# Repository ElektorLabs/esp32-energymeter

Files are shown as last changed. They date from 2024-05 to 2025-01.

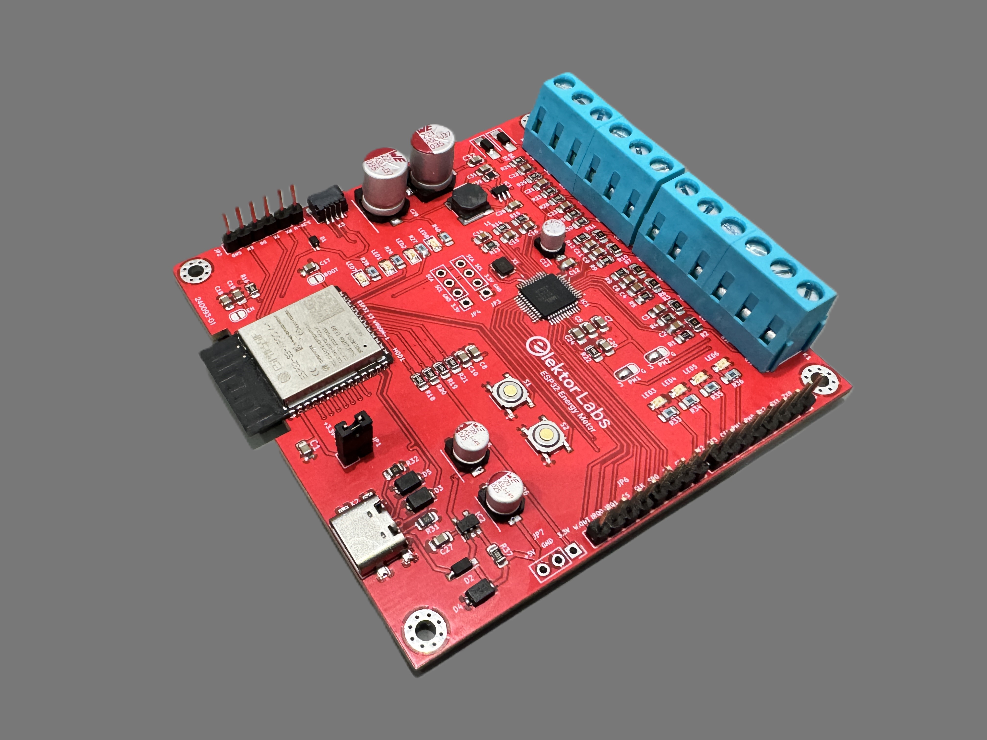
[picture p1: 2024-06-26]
images/IMG_0345.JPG

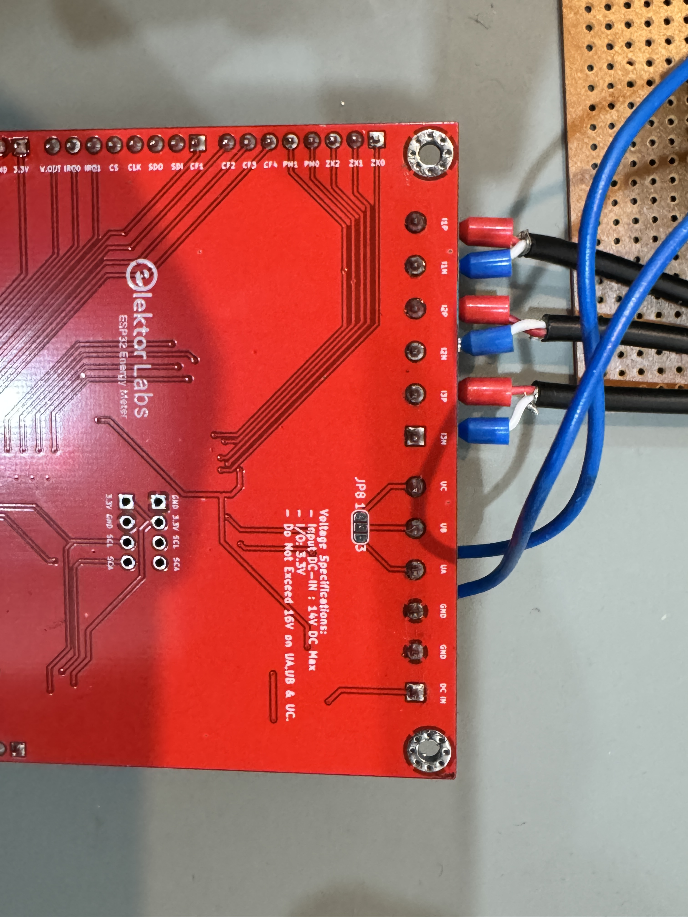
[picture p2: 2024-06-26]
images/IMG_0416.JPG

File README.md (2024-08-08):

# ESP32 Energy Meter

Welcome to the official repository for the ESP32 Energy Meter, an energy monitoring project developed by Elektor Labs. This repository hosts all the necessary design files, code, and documentation to build and deploy a safe energy meter using the ESP32-S3 microcontroller.

## Project Overview

The ESP32 Energy Meter utilizes the Espressif ESP32-S3 microcontroller and the ATM90E32AS IC from Microchip for precise energy measurement across single and three-phase systems. This version includes significant safety and functionality enhancements, including a transformer-based power supply and modularity for diverse applications.

## Features

- **High Precision:** Uses ATM90E32AS IC for accurate energy data.
- **Enhanced Safety:** Transformer-based power reduces direct exposure to high voltages.
- **Flexible Configuration:** Supports both single-phase and three-phase installations.
- **Smart Home Integration:** Easily integrates with Home Assistant for advanced energy management.
- **Customizable Firmware:** Includes ESPHome YAML configurations for easy adaptation and updates.

## Repository Contents

- `/hardware` - Electronic schematic files.
- `/hardware` - PCB design files suitable for manufacturing.
- `/src/ESPHome` - ESPHome YAML configuration files.

## Getting Started

### Prerequisites

Components used in this project are mention in the BOM list `/hardware/production/BOM-esp32-energymeter-V2.xlsx`, overview of the components and required tools are as follows:
- ESP32-S3 module
- ATM90E32AS IC
- Step-down transformer (220V AC to 12V AC) - Preferably a bell transformer
- Current Transfomers - YDHC SCT 013 100A 50mA
- Passive components (resistors, capacitors)
- Tools for PCB assembly and soldering

### Setup Instructions

1. **Clone the repository:**
   ```bash
   git clone https://github.com/ElektorLabs/esp32-energymeter.git
   ```
2. **PCB Assembly:**
   - Refer to the `/hardware` directory and manufacture the PCB using the provided design files.
   - Solder the components onto the PCB as per the layout and schematic details in the `/Schematics` folder.

3. **Firmware Installation:**
   - Navigate to the `/src/ESPHome` directory.
   - Update the YAML file with your specific network details and preferences.
   - Flash the firmware to the ESP32-S3 using ESPHome through the command line or ESPHome Dashboard.

4. **Integrate with Home Assistant:**
   - Follow the integration guide in the article to connect the energy meter to Home Assistant.
   - Monitor and manage your energy consumption directly through the Home Assistant interface.

## Calibration and Testing

- After assembly, perform a calibration check as described in the article to ensure accuracy.
- Test the device under different load conditions to verify the setup and adjust the calibration if necessary.

## Contributing

Your contributions are welcome! If you have enhancements, fixes, or improvements, please fork this repository and submit a pull request with your changes. For substantial modifications or new features, please open an issue to discuss them first.

## License

This project is distributed under the MIT License - see the LICENSE file for details.

## Acknowledgments

- Thanks to Espressif Systems for the ESP32 technology.
- Thanks to Microchip for the energy measurement IC.
- Gratitude to all community members who have contributed to refining this project.

## Contact

For further inquiries or support, feel free to reach out through GitHub issues or the project discussion board.

---

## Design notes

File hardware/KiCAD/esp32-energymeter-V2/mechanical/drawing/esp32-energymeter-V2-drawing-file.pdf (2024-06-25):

3

2

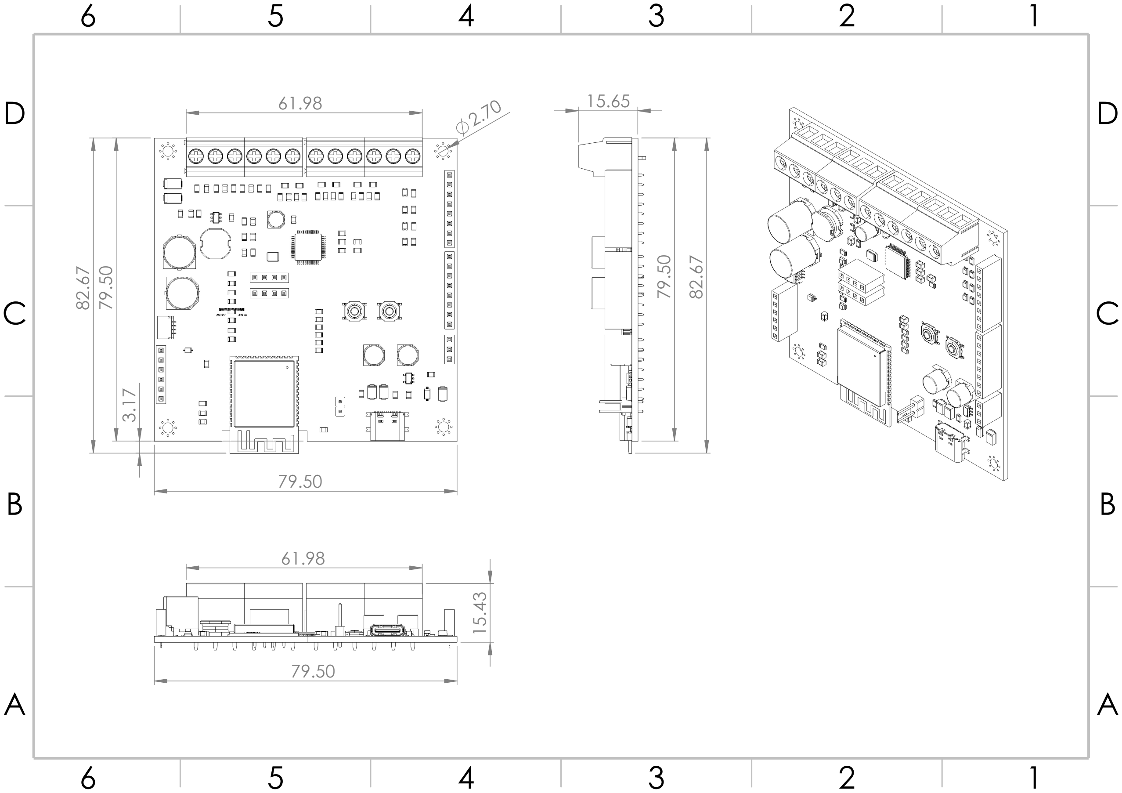
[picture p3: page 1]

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
2.70 82.67

### 79.50 ⁷⁹.50 3.17

61.98 82.67

15.65 79.50

79.50 15.43

61.98

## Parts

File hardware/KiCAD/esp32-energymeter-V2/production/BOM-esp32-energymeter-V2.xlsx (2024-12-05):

Date: | 2024-03-01 16:43
Ref | Mouser Number | Qty | Value | Description
C1, C5, C7, C8, C10, C12, C17, C18, C19, C20, C24, C27, C28, C31, C32 | 80-C0805C104M5RAC | 15 | 100nF | Unpolarized capacitor
C2, C3, C4, C6, C9, C11, C14, C15, C16, C21, C22, C23 | 80-C0805C183K2RACTU | 12 | 18nF | Unpolarized capacitor
C13 | 710-865090340001 | 1 | 4.7uF | Wurth Elektronik 4.7uF 16 V dc Aluminium Electrolytic Capacitor, WCAP-ASLU Series 1000h 5.5 (Dia.) x 3.85mm
C25, C26 | 710-865080442004 | 2 | 22uF | Wurth Elektronik 22uF Electrolytic Capacitor 25V 20% Surface Mount - 865080442004
C29, C30 | 710-865080553014 | 2 | 220uF | Wurth Elektronik 220uF 35 V dc Aluminium Electrolytic Capacitor, WCAP-ASLI Series 2000h 8 (Dia.) x 10.35mm
D1 | 621-BAT760-7 | 1 | BAT760-7 | Diode Schottky 30V 1A 2Pin SOD323 Diodes Inc BAT760-7, SMT Schottky Diode, 30V 1A, 2-Pin SOD-323
D2 | 621-1N5819HW-F | 1 | 1N5819HW-7-F | Diode Schottky 1A 40V SOD123 Diodes Inc 1N5819HW-7-F, SMT Schottky Diode, 40V 1A, 2-Pin SOD-123
D3, D4, D5 | 576-SZSMF4L5.0AT3G | 3 | SZSMF4L5.0AT3G | Automotive Surface Mount 400 W TVS Diode in SOD-123FL
D6,D7 | 621-B140HW-7 | 1 | B140HW-7 | Diodes Inc B140HW-7, SMT Schottky Diode, 40V 1A, 2-Pin SOD-123
IC1 | 556-ATM90E32AS-AU-R | 1 | ATM90E32AS-AU-R
IC2 | 513-NJM2882F33-TE1 | 1 | NJM2882F33-TE1 | LDO Voltage Regulators 75dB 30uVrms 300mA 1.0uF 3.3V 350mW
IC3 | 621-AP63203WU-7 | 1 | AP63203WU-7 | Switching Voltage Regulators DCDC Conv HV Buck TSOT26 T&R 3K
K1, K4 | 490-TB004-508-06BE | 2 |  | Terminal block, screw type, 5.08 , horizontal, 6 poles, CUI Blue
K2 | 523-GSB1C41110SSHR | 1 | GSB1C41110SSHR | USB2.0, Type C, Top mount, Center Height 1.63mm, Single Row Surface Mount
L1 | 652-SRN6028C-3R9M | 1 | 3.9uH | Ind,6.0x6.0x2.6mm,3.9uH+/-20%,3.3A,shd
LED3, LED4, LED5, LED6 | 710-150080YS75000 | 4 | Yellow Led | Light emitting diode
MOD1 | 356-ESP32-S3WRM1N8R2 | 1 | ESP32-S3-WROOM-1 | 2.4 GHz WiFi (802.11 b/g/n) and Bluetooth Â® 5 (LE) module Built around ESP32S3 series of SoCs, Xtensa Â® dualcore 32bit LX7 microprocessor Flash up to 16 MB, PSRAM up to 8 MB 36 GPIOs, rich set of peripherals Onboard PCB antenna
R1, R4, R5, R8, R9, R12, R13, R14, R15, R23, R24, R25 | 652-CHP0805FX1001ELF | 12 | 1k | Resistor
R2, R3, R6, R7, R10, R11 | 755-SDR10EZPJ2R4 | 6 | 2R4 | Resistor
R16, R18, R19, R20, R21, R22 | 652-CMP0805-FX-1002L | 6 | 10k | Resistor
R28, R29, R30, R37 | 652-CMP0805-FX-1003L | 4 | 100k | Resistor
R31, R32 | 755-SDR10EZPJ472 | 2 | 4.7k | Resistor
R26, R27, R33, R34, R35, R36, R38, R40 | 660-RK73H2ATTD80R6F | 8 | 80R | Resistor
R39 | 71-RCS08050000Z0EA | 1 | 0R | Resistor
S1, S2 | 611-PTS526SM15SMTR2L | 2 |  | Tactile Switches 50mA 12VDC, 5.2x5.2mm, 1.5mm H, 160gf, G leads, No ground pin, metal actuator
X1 | 815-ABM8G-16.3-B4Y-T | 1 |  | 16.384 MHz +/-30ppm Crystal 10pF 80 Ohms 4-SMD, No Lead
LED1, LED 7, LED 8 | 710-150080RS75000 | 3 | Red | Light emitting diode
LED2 | 710-150080GS75000 | 1 | Green Led
JP1 |  | 1 |  | PinHeader_1x02_P2.54mm_Vertical
JP2 |  | 1 |  | PinHeader_1x06_P2.54mm_Vertical
JP3 |  | 1 |  | PinHeader_1x04_P2.54mm_Vertical
JP4 |  | 1 |  | PinHeader_1x04_P2.54mm_Vertical
JP5, JP6 |  | 2 |  | PinHeader_1x08_P2.54mm_Vertical
JP7 |  | 1 |  | PinHeader_1x03_P2.54mm_Vertical
Options for Step Down Voltage Transformers
Navaris deurbeltransformator - 8V, 12V, 24V |  | https://amzn.eu/d/h4jTlUE
Honeywell E3539N beltransformator VDE 2 - 12V |  | https://amzn.eu/d/geya4uD
Honeywell E3554N Klingeltransormator VDE 3 - 8V |  | https://amzn.eu/d/geya4uD
Current Transformer
YHDC SCT 013 100A-50mA |  | https://www.poweruc.pl/products/split-core-current-transformer-sct013-rated-input-5a-100a

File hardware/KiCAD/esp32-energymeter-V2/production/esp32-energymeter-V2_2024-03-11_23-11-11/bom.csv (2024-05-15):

Designator | Footprint | Quantity | Value | LCSC Part #
BOOT1 | SolderJumper-2_P1.3mm_Open_RoundedPad1.0x1.5mm | 1 | BOOT
C1, C10, C28, C32, C8 | 0805 | 5 | 100nF 50V
C11, C14, C15, C16, C2, C3, C4, C6, C9 | 0805 | 9 | 18nF
C12, C17, C18, C19, C5 | 0805 | 5 | 0.1uF
C13 | CAPAE430X550N | 1 | 10 uF
C20, C24, C31 | 0805 | 3 | 100nF
C21, C22, C23 | 0805 | 3 | 18nF 50V
C25, C26 | CAPAE530X550N | 2 | 22uF
C27 | 0805 | 1 | 0.01uF
C29, C30 | CAPAE830X1050N | 2 | 220uF
C7 | 0805 | 1 | 10uF 10V
D1 | SOD2513X120N | 1 | BAT760-7
D2 | SOD3716X145N | 1 | 1N5819HW-7-F
D3, D4, D5 | SODFL3824X140N | 3 | SZSMF4L5.0AT3G
D6, D7 | D_SMA | 2 | B140HW-7
EN1 | SolderJumper-2_P1.3mm_Open_RoundedPad1.0x1.5mm | 1 | EN
H1, H2, H3, H4 | MountingHole_2.7mm_Pad_Via | 4 | MountingHole_Pad
IC1 | QFP50P900X900X120-48N | 1 | ATM90E32AS-AU-R
IC2 | SOT95P280X130-5N | 1 | NJM2882F33-TE1
IC3 | SOT95P280X100-6N | 1 | AP63203WU-7
JP1 | PinHeader_1x02_P2.54mm_Vertical | 1 | JUMPER
JP2 | PinSocket_1x06_P2.54mm_Vertical | 1 | Conn_01x06
JP3 | PinSocket_1x04_P2.54mm_Vertical | 1 | OLED-A
JP4 | PinSocket_1x04_P2.54mm_Vertical | 1 | OLED-B
JP5, JP6 | PinSocket_1x08_P2.54mm_Vertical | 2 | Conn_01x08
JP7 | PinSocket_1x03_P2.54mm_Vertical | 1 | Conn_01x03
JP8, PM1, PM2 | SolderJumper-3_P1.3mm_Open_RoundedPad1.0x1.5mm_NumberLabels | 3 | SolderJumper_3_Open
K1, K4 | TerminalBlock_RND_205-00236_1x06_P5.08mm_Horizontal | 2 | Screw_Terminal_01x06
K2 | GSB1C41110SSHR | 1 | GSB1C41110SSHR
K3 | JST_SH_SM04B-SRSS-TB_1x04-1MP_P1.00mm_Horizontal | 1 | Qwiic
L1 | SRN6028C3R9M | 1 | SRN6028C-3R9M
LED1, LED7, LED8 | 0805 | 3 | NCD0805R1
LED2 | 0805 | 1 | NCD0805G1
LED3 | LEDM2012X80N | 1 | 150080RS75000
LED4 | LEDM2012X80N | 1 | 150080GS75000
LED5 | LEDM2012X80N | 1 | 150080BS75000
LED6 | LEDM2012X80N | 1 | 150080AS75000
MOD1 | ESP32-S3-WROOM-1 | 1 | ESP32-S3-WROOM-1
R1, R12, R13, R14, R15, R23, R24, R25, R4, R5, R8, R9 | 0805 | 12 | 1k
R10, R11, R2, R3, R6, R7 | 0805 | 6 | 2R4
R16, R18, R19, R20, R21, R22 | 0805 | 6 | 10K
R26, R27, R33, R34, R35, R36, R38, R40 | 0805 | 8 | 80R
R28, R29, R30, R37 | 0805 | 4 | 100k
R31, R32 | 0805 | 2 | 4.7k
R39 | 0805 | 1 | 0R
S1, S2 | PTS526SM15SMTR2LFS | 2 | PTS526_SM15_SMTR2_LFS
X1 | ABM8G | 1 | ABM8G-16.384MHZ-B4Y-T

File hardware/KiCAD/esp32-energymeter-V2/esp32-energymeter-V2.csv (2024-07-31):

Date: | 31/07/2024 19:06
Tool: | Eeschema 7.0.7
Component Count: | 114
Ref | Qnty | Value | Cmp name | Footprint | Description | Vendor | DNP
BOOT1 | 1 | BOOT | Jumper_2_Open | Jumper:SolderJumper-2_P1.3mm_Open_RoundedPad1.0x1.5mm | Jumper, 2-pole, open
C1, C5, C7, C8, C10, C12, C17, C18, C19, C20, C24, C27, C28, C31, C32 | 15 | 100nF | C_Small | Capacitor_SMD:C_0805_2012Metric_Pad1.18x1.45mm_HandSolder | Unpolarized capacitor, small symbol
C2, C3, C4, C6, C9, C11, C14, C15, C16, C21, C22, C23 | 12 | 18nF | C_Small | Capacitor_SMD:C_0805_2012Metric_Pad1.18x1.45mm_HandSolder | Unpolarized capacitor, small symbol
C13 | 1 | 4.7uF | 8.6509E+11 | SamacSys_Parts:CAPAE430X550N | Wurth Elektronik 4.7uF 16 V dc Aluminium Electrolytic Capacitor, WCAP-ASLU Series 1000h 5.5 (Dia.) x 3.85mm
C25, C26 | 2 | 22uF | 8.6508E+11 | CAPAE530X550N | Wurth Elektronik 68uF Electrolytic Capacitor 6.3V dc Surface Mount - 865080442004
C29, C30 | 2 | 220uF | 8.65081E+11 | CAPAE830X1050N | Wurth Elektronik 220uF 35 V dc Aluminium Electrolytic Capacitor, WCAP-ASLI Series 2000h 8 (Dia.) x 10.35mm
D1 | 1 | BAT760-7 | BAT760-7 | SOD2513X120N | Diode Schottky 30V 1A 2Pin SOD323 Diodes Inc BAT760-7, SMT Schottky Diode, 30V 1A, 2-Pin SOD-323
D2 | 1 | 1N5819HW-7-F | 1N5819HW-7-F | SOD3716X145N | Diode Schottky 1A 40V SOD123 Diodes Inc 1N5819HW-7-F, SMT Schottky Diode, 40V 1A, 2-Pin SOD-123
D3, D4, D5 | 3 | SZSMF4L5.0AT3G | SZSMF4L5.0AT3G | SODFL3824X140N | Automotive Surface Mount 400 W TVS Diode in SOD-123FL
D6, D7 | 2 | B140HW-7 | B140-E3 | Diode_SMD:D_SMA | 40V 1A Schottky Barrier Rectifier Diode, SMA(DO-214AC)
EN1 | 1 | EN | Jumper_2_Open | Jumper:SolderJumper-2_P1.3mm_Open_RoundedPad1.0x1.5mm | Jumper, 2-pole, open
H1, H2, H3, H4 | 4 | MountingHole_Pad | MountingHole_Pad | MountingHole:MountingHole_2.7mm_Pad_Via | Mounting Hole with connection
IC1 | 1 | ATM90E32AS-AU-R | ATM90E32AS-AU-R | ATM90E32AS-AU-R:QFP50P900X900X120-48N
IC2 | 1 | NJM2882F33-TE1 | NJM2882F33-TE1 | SOT95P280X130-5N | LDO Voltage Regulators LDO
IC3 | 1 | AP63203WU-7 | AP63203WU-7 | SOT95P280X100-6N | Switching Voltage Regulators DCDC Conv HV Buck TSOT26 T&R 3K
JP1 | 1 | JUMPER | Conn_01x02 | Connector_PinHeader_2.54mm:PinHeader_1x02_P2.54mm_Vertical | Generic connector, single row, 01x02, script generated (kicad-library-utils/schlib/autogen/connector/)
JP2 | 1 | Conn_01x06 | Conn_01x06 | Connector_PinSocket_2.54mm:PinSocket_1x06_P2.54mm_Vertical | Generic connector, single row, 01x06, script generated (kicad-library-utils/schlib/autogen/connector/)
JP3 | 1 | OLED-A | Conn_01x04 | Connector_PinSocket_2.54mm:PinSocket_1x04_P2.54mm_Vertical | Generic connector, single row, 01x04, script generated (kicad-library-utils/schlib/autogen/connector/)
JP4 | 1 | OLED-B | Conn_01x04 | Connector_PinSocket_2.54mm:PinSocket_1x04_P2.54mm_Vertical | Generic connector, single row, 01x04, script generated (kicad-library-utils/schlib/autogen/connector/)
JP5, JP6 | 2 | Conn_01x08 | Conn_01x08 | Connector_PinSocket_2.54mm:PinSocket_1x08_P2.54mm_Vertical | Generic connector, single row, 01x08, script generated (kicad-library-utils/schlib/autogen/connector/)
JP7 | 1 | Conn_01x03 | Conn_01x03 | Connector_PinSocket_2.54mm:PinSocket_1x03_P2.54mm_Vertical | Generic connector, single row, 01x03, script generated (kicad-library-utils/schlib/autogen/connector/)
JP8 | 1 | SolderJumper_3_Open | SolderJumper_3_Open | Jumper:SolderJumper-3_P1.3mm_Open_RoundedPad1.0x1.5mm_NumberLabels | Solder Jumper, 3-pole, open
K1, K4 | 2 | Screw_Terminal_01x06 | Screw_Terminal_01x06 | TerminalBlock_RND:TerminalBlock_RND_205-00236_1x06_P5.08mm_Horizontal | Generic screw terminal, single row, 01x06, script generated (kicad-library-utils/schlib/autogen/connector/)
K2 | 1 | GSB1C41110SSHR | GSB1C41110SSHR | GSB1C41110SSHR | USB2.0, Type C, Top mount, Center Height 1.63mm, Single Row Surface Mount
K3 | 1 | Qwiic | Conn_01x04_MountingPin | Connector_JST:JST_SH_SM04B-SRSS-TB_1x04-1MP_P1.00mm_Horizontal | Generic connectable mounting pin connector, single row, 01x04, script generated (kicad-library-utils/schlib/autogen/connector/)
L1 | 1 | SRN6028C-3R9M | SRN6028C-3R9M | SRN6028C3R9M | Ind,6.0x6.0x2.6mm,3.9uH+/-20%,3.3A,shd
LED1, LED7, LED8 | 3 | NCD0805R1 | LED | LED_SMD:LED_0805_2012Metric_Pad1.15x1.40mm_HandSolder | Light emitting diode
LED2 | 1 | NCD0805G1 | LED | LED_SMD:LED_0805_2012Metric_Pad1.15x1.40mm_HandSolder | Light emitting diode
LED3 | 1 | 150080RS75000 | 150080RS75000 | SamacSys_Parts:LEDM2012X80N | LED,Wurth Elektronik,150080RS75000 Wurth Elektronik 150080RS75000, WL-SMCW Series Red LED, 625 nm 2012 (0805) Clear, Rectangle Lens SMD package
LED4 | 1 | 150080GS75000 | 150080RS75000 | SamacSys_Parts:LEDM2012X80N | LED,Wurth Elektronik,150080RS75000 Wurth Elektronik 150080RS75000, WL-SMCW Series Red LED, 625 nm 2012 (0805) Clear, Rectangle Lens SMD package
LED5 | 1 | 150080BS75000 | 150080RS75000 | SamacSys_Parts:LEDM2012X80N | LED,Wurth Elektronik,150080RS75000 Wurth Elektronik 150080RS75000, WL-SMCW Series Red LED, 625 nm 2012 (0805) Clear, Rectangle Lens SMD package
LED6 | 1 | 150080AS75000 | 150080RS75000 | SamacSys_Parts:LEDM2012X80N | LED,Wurth Elektronik,150080RS75000 Wurth Elektronik 150080RS75000, WL-SMCW Series Red LED, 625 nm 2012 (0805) Clear, Rectangle Lens SMD package
MOD1 | 1 | ESP32-S3-WROOM-1 | ESP32-S3-WROOM-1 | PCM_Espressif:ESP32-S3-WROOM-1 | 2.4 GHz WiFi (802.11 b/g/n) and Bluetooth ® 5 (LE) module Built around ESP32S3 series of SoCs, Xtensa ® dualcore 32bit LX7 microprocessor Flash up to 16 MB, PSRAM up to 8 MB 36 GPIOs, rich set of peripherals Onboard PCB antenna
PM1, PM2 | 2 | SolderJumper_3_Open | SolderJumper_3_Open | Jumper:SolderJumper-3_P1.3mm_Open_RoundedPad1.0x1.5mm_NumberLabels | Solder Jumper, 3-pole, open
R1, R4, R5, R8, R9, R12, R13, R14, R15, R23, R24, R25 | 12 | 1k | R_US | Resistor_SMD:R_0805_2012Metric_Pad1.20x1.40mm_HandSolder | Resistor, US symbol
R2, R3, R6, R7, R10, R11 | 6 | 2R4 | R_US | Resistor_SMD:R_0805_2012Metric_Pad1.20x1.40mm_HandSolder | Resistor, US symbol
R16, R18, R19, R20, R21, R22 | 6 | 10k | R_US | Resistor_SMD:R_0805_2012Metric_Pad1.20x1.40mm_HandSolder | Resistor, US symbol
R26, R27, R33, R34, R35, R36, R38, R40 | 8 | 80R | R_US | Resistor_SMD:R_0805_2012Metric_Pad1.20x1.40mm_HandSolder | Resistor, US symbol
R28, R29, R30, R37 | 4 | 100k | R_US | Resistor_SMD:R_0805_2012Metric_Pad1.20x1.40mm_HandSolder | Resistor, US symbol
R31, R32 | 2 | 4.7k | R_US | Resistor_SMD:R_0805_2012Metric_Pad1.20x1.40mm_HandSolder | Resistor, US symbol
R39 | 1 | 0R | R_US | Resistor_SMD:R_0805_2012Metric_Pad1.20x1.40mm_HandSolder | Resistor, US symbol
S1, S2 | 2 | PTS526_SM15_SMTR2_LFS | PTS526_SM15_SMTR2_LFS | PTS526SM15SMTR2LFS | Tactile Switches 50mA 12VDC, 5.2x5.2mm, 1.5mm H, 160gf, G leads, No ground pin, metal actuator
X1 | 1 | ABM8G-16.384MHZ-B4Y-T | ABM8G-16.384MHZ-B4Y-T | ABM8G | 16.384 MHz +/-30ppm Crystal 10pF 80 Ohms 4-SMD, No Lead

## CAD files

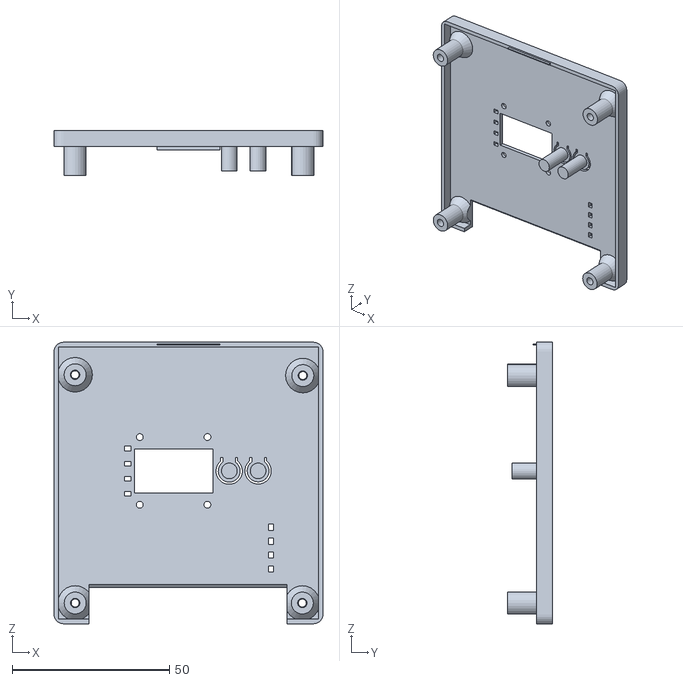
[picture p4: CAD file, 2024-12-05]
hardware/KiCAD/esp32-energymeter-V2/enclosure/Enclosure_top-cover-v1.STL
85.5 x 14.4 x 89.5

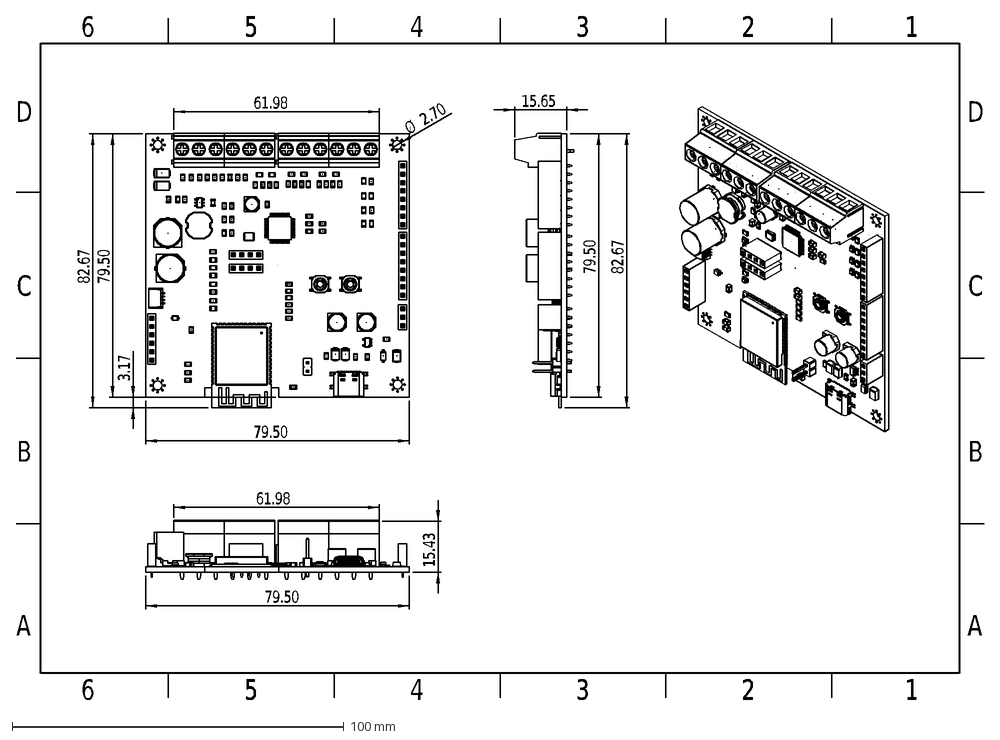
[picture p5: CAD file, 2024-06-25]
hardware/KiCAD/esp32-energymeter-V2/mechanical/drawing/esp32-energymeter-V2.DXF
A
B
C
D
6
5
4
3
2
1
79.50
3.17
Ø
2.70
82.67
61.98
15.65
15.43

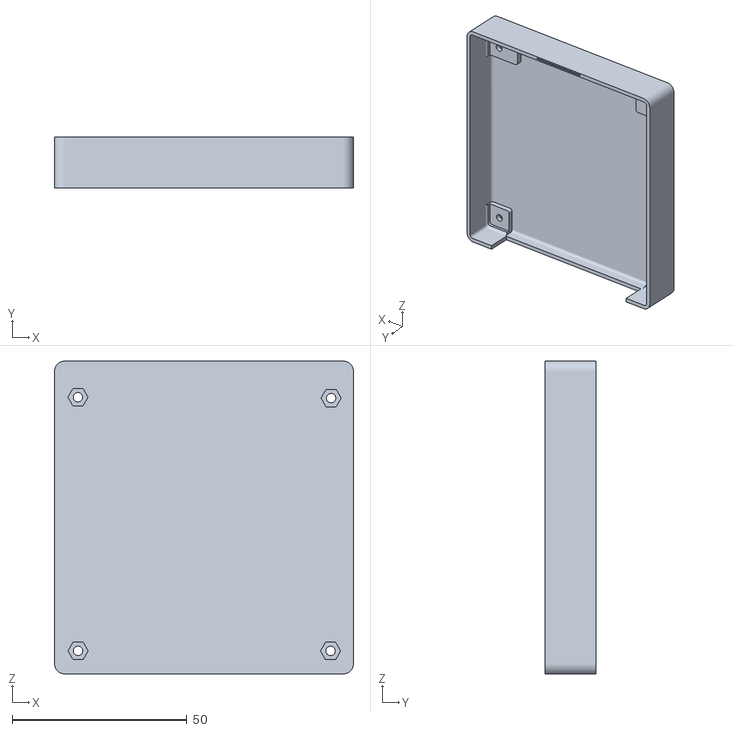
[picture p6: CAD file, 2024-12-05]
hardware/KiCAD/esp32-energymeter-V2/enclosure/Enclosure_base-v1.STL
85.5 x 14.5 x 89.5

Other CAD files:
hardware/KiCAD/esp32-energymeter-V2/mechanical/drawing/esp32-energymeter-V2.DWG

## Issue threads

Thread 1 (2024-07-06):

typo?

dbuggz, 2024-07-06:
just reading through your code it looks like a typing error in src/ESPHome/esp32-energymeter.yaml, line 67-68. Do you mean ct2Amps? Also need to change line 83.

      current:
        name: "CT2 Current"
        id: ct3Amps

line 82-83
      current:
        name: " CT3 Current"
        id: ct2Amps

Regards
Dave

Saad-Imtiaz, 2024-07-07:
Hi Dave,

Yes,I believe it is, thanks for pointing it out.

Regards,
Saad

Closed 2024-07-07.

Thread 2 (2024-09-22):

USB-C Surge protecion

JmanNZ, 2024-09-22:
Hi
With D3 and D5 fitted the detected USB device is unrecognised. Removing D3 and D5 resolves the issue.
Burden resistors at 4.8 ohms this seems a little low would 6.8 ohms be a better value?

Thank you for the great project.

Saad-Imtiaz, 2024-09-22:
Thank you for your feedback and for bringing this to my attention!

Regarding the issue with D3 and D5, it’s possible that these diodes might be affecting the USB communication, depending on their specific characteristics or placement in the circuit. I’ll investigate this further, but I’m glad to hear that removing them resolves the issue. If you prefer, you can leave them out if the device works as expected without them.

Burden resistors, 4.8 was selected as a compromise between sensitivity and power dissipation, but you're right – in some applications, it may come out to be 6.8, as it dissipates slightly less power. This value can be used when the case makes this value come out best for the measurement rather than 4.8. Sometimes burden resistor values may even be chosen based on whether the case suits that application where the sensitivity requirements for the measurement suggest this value.

Thanks again for your kind words and for trying the project!

Closed 2024-10-17.

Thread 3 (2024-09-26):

STL / Reset

JmanNZ, 2024-09-26:
Hi
Could you please post the STL file the case.
I noticed that the ESP32S3 does not reset sometimes on powerup, Removing C18 has completely solved the issue for me.

Thanks again from me and my Home Assistant :)

elektor-labs, 2024-11-18:
Hi @JmanNZ

Thank you for the feedback!

I've added the STL files for the enclosure to the repository. You can find them here:
```hardware/KiCAD/esp32-energymeter-V2/enclosure```

Tip: For best results, consider printing it with PETG filament.

I'm really glad you enjoyed the project! 😊

Closed 2024-11-18.

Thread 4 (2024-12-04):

business case feedback

temphstarmans, 2024-12-04:
**Abstract**
I would advice to target the industrial market.  Shelly Pro 3EM seems a better fit for most consumer problems. A further challenge, is that consumers pay tax. Industrial customers have fiscal options to avoid these. For industrial customers you could differentiate yourself by providing additional services like; Overall Equipment Effectiveness (OEE) and anomaly detection. You could also measure other things like temperature and humidity (e.g. via chip Sensirion SHTC3). This is critical for injection molding machines. In the industrial customer space there is a lot of activity and companies like [Sensorfact](https://www.sensorfact.eu) raised over [25 million euro's](https://www.eu-startups.com/2023/07/utrecht-based-climate-tech-sensorfact-raises-e25-million-to-smart-monitor-resources-for-industrial-smes/).  There is a lot of old industrial equipment which needs additional features. Power needs to be measured to prevent fines or meet environmental regulations. Industrial customers typically need additional algorithms for their specific use case. To meet this, I would do the following;

- improve the encasing, don't 3D print but use for instance apraRail DB 3 Module, part [449-330-45](https://www.apra.de/produkte/apra-rail-db-serie/) at 7.59 euro's
- add ethernet, e.g. [W5500](https://docs.wiznet.io/Product/iEthernet/W5500/ref-schematic) or test wifi is strong enough to penetrate the metal shielding of industrial machines (din rail is inside machine)
- ensure board can be DIN rail mounted
- target 400V
- PoE could be provided via USB C to ethernet. Ethernet can not be converted to USB as the drivers are lacking on the ESP32.  A PoE reference design can be found here https://github.com/OLIMEX/ESP32-POE/ and https://imgur.com/wqMsZ2o . It is not easy to add, as it requires galvanic isolation. As such, I would see if can be done via ethernet to USB c converter ( price around 8 euro's)
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

- retrieve power via voltage measurement, example use RAC05-05SK/480 to convert 400V to 5V.
- provide a battery powered solution leveraging the ULP of the ESP32 and ESPnow packets
  see (https://github.com/glenn20/upy-esp32-experiments). Battery powered version would only measure current.
- fixed price around 200 euro's is not uncommon, with software features you could target higher
- you could argue that open-source makes your product more secure
- you could let PCBway make your product and just provide additional software

**Introduction**
In the following, I will provide a literature overview.
The energy meter can be used for consumer or industrial applications. The business model can be subscription or non-subscription based.  A further separation is possible on communication protocol used.
Finally, energy meters can only measure current or voltage and current.

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

Firstly, I will review hardware. This is further dived in consumer and industrial equipment.
Lora based equipment is reviewed separately. Finally, I will review software companies.

**Hardware**

Some of the options mentioned require subscription others a fixed fee. Difference is not always clear from documentation.

**Consumer**
Shelly Pro 3EM
[Shelly](https://www.shelly.com/products/shelly-pro-3em-x1) uses ESP32-D0WDQ6, price is 145.08 euro.
Features: DIN rail, MQTT, supply via voltage  measurement, ethernet, 3 phases measures current and voltage
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

Tuya Smart Life meter.
Price 36 euro
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

**Industrial**
[NR30IoT](https://www.lumel.com.pl/en/catalogue/product/rail-mounted-3-phase-power-network-meter-with-recording-dedicated-to-iot-applications)
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
Features: DIN rail, MQTT, DC voltage supply, ethernet, 3 phases measures current and voltage
Price:  667 euro’s including VAT, [link](https://www.digikey.nl/nl/products/detail/lumel/NR30IoT-1221MSM0/22218035)

[AdW00 Acrel 4G/Wifi](https://www.acrel.gr/products/adw300-wireless-energy-meter/)
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
Features:  DIN rail, MQTT, wifi, 3 phases measures current and voltage
                   power supplied via voltage measurement
Other:   might require subscription, documentation not clear
Price:  200 euro’s see [AliExpress](https://nl.aliexpress.com/item/1005006257640590.html)

[Kompere KPM37](https://www.comperepower.com/product/kpm37-din-rail-lora-three-phase-energy-meter.html)
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
Features: Din rail, 4G, MQTT, wifi, 3 phases measures current and voltage
Other: Documentation is not [clear](https://v4-upload.digoodcms.com/267/file_1701744455_New-KPM37.pdf)
Price: 150 euro’s see [aliexpress](https://nl.aliexpress.com/item/1005005964543503.html?gatewayAdapt=glo2nld)

https://www.iammeter.com
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

**Lora**

Solutions in the lora space target applications where there is no voltage measurement and the sensor must be powered via battery. Your can make your solution battery powered. You would need to use the ULP processor and experiments listed here https://github.com/glenn20/upy-esp32-experiments .

R718N17 LoRaWAN 1-Phase current sensor 75A
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

Pressac
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
Protocol Enocean (propietary), communication range 30-100 foot
Sensors are used by Sensorfact

https//ncd.io
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

**Software**
A company typically needs an enterprise resource planning (ERP) system.  A manufacturing company also needs a Manufacturing Execution System (MES). A MES system needs sensors,
as such there are also MES companies which provide energy sensors, e.g. https://bmsvision.com/products/energymaster.
Off-topic, the most open source ERP available is https://erpnext.com/. It doesn't really provide a MES system though.
Several startups are active in the energy sensor segment. The product is of interest as it has the following properties; artificial intelligence (possible due to the availability of data), environment (possible due to energy savings), industry ( in the industry you need to know carbon dioxide emission and energy usage, companies can get a very big fine if they use too much energy).

**Sensorfact**
Sensorfact is a good example as it is from the Netherlands, like Elektor. Also it's business started with mainly energy sensors. They now also offer other options like gas pressure sensors. I was surprised that sensorfact doesn't make its own sensors, but uses the sensors made by Pressac. As customer you pay a monthly fee per sensor and per bridge. The bridge converts the Enocean protocol to ethernet/wifi. Sensorfact than transfers all data to their platform where they provide some additional insights via their portal. Price is around 220 euro's per year; assuming you have multiple sensors and can share 3 sensors per bridge. Below is the calculation
(12*(12.5 (price sensor per month)+1/3*17.5 (price bridge per month))) ~ €220 per year
You need an additional subscription if you want to download data.
Good for you to know is that this model works. These prices are paid.

The following two VC backed startups are also active in this space.  I did not yet look into them.
- [Meazon](https://meazon.com/)
- [Budderfly](https://case-studies.budderfly.com/sonic-outsourcing-case-study)

**Other links**
https://openenergymonitor.org/
Provides good overview of how an energy sensor works, https://docs.openenergymonitor.org/electricity-monitoring, but using an ATM90E32AS IC is a much better solution.

There is also this youtube video with over 500K views it seems to be based around the open energymonitor documentation
https://youtu.be/PSzkaSy5lHY?si=oeXtccgTqzCVhAGn

Closed 2025-05-20.

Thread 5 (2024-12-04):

technical feedback

temphstarmans, 2024-12-04:
I appreciate the project. As telling what is great about it doesn't really help.

I provide the following suggestions;

- transition to kicad 8
- 3D models are incomplete
- replace leds with CLMVC-FKA-CL1D1L71BB7C3C3 to reduce number of components
- add a field called manf# to fix kicost integration https://github.com/hildogjr/KiCost
- you can create 3D renders via https://github.com/30350n/pcb2blender
-  I would use multiple sheets in my kicad schema and separate measurement from microcontroller
- you can probably drop the fabrication folder, this can be generated via PCBWAY plugin or kicost plugin (most manufacturers provide plugin)
- it could be nice to enter debug mode without adding or removing a jumper. A standard esp32 dev kit uses chip in combination with USB C which allows entering debug and flash mode without interaction. This might be desirable in the field for industrial applications.

My most important feedback. Think hard about the encasing.  Most customers will only understand this. You project is not presentable to non technical audience with 3D printed encasing. I think a screen is not needed. A thing you could consider is https://github.com/witnessmenow/ESP32-Cheap-Yellow-Display

- I looked at apraRail DB 3 Module, part [449-330-45](https://www.apra.de/produkte/apra-rail-db-serie/), click on 3D daten in the link to get the CAD file. Price is 7.59 euro's.  The top can be kept open for screen. It is the only encasing I could find with CAD file. Naturally, the OSHW way of doing this would be leveraging the assembly module in [FreeCAD 1.0RC](https://www.freecad.org/) and the [Kicad StepUp workbench](https://www.kicad.org/external-tools/stepup/). FreeCAD is not perfect but should definitely be sufficient for this project.

PS.
-  do you use https://git-lfs.com/  to track movies and jpgs?
- Non-intrusive voltage measurements could be good research direction see [Non-intrusive voltage measurement of ac power lines](https://ietresearch.onlinelibrary.wiley.com/doi/10.1049/el.2016.3935). This could be cool for an elektor article. There is 2024 paper which got a high accuracy... lost the reference..

Closed 2025-05-20.

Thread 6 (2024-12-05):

legal feedback

temphstarmans, 2024-12-05:
I would add a section with the legal requirements you need to meet for bringing this board to the market. Most likely, 3D printed encasing is not compliant.

## Requirements

**International Standards**
**IEC 62052-11:** This standard covers general requirements, tests, and test conditions for alternating current (AC) metering equipment
**IEC 62053-21:** This standard outlines specific requirements for static meters used for active energy measurement, including accuracy classes.
**IEC 62053-23:** This standard addresses specific requirements for static meters used for reactive energy measurement.

**European Standards:**
**Directive 2014/35/EU:**   Low voltage Directive (LVD)
**EN 301 893:** Standard which covers Wifi
**EN 62053-21:** This European standard is equivalent to IEC 62053-21 and covers static meters for active energy.
**EN 62053-23:**  This European standard is equivalent to IEC 62053-23 and covers static meters for reactive energy 

## Meeting of requirements

**Measurement**
Metering features fully in compliance with the requirements of IEC62052-11, IEC62053-22 and IEC62053-23, ANSI C12.1 and ANSI C12.20; applicable in poly-phase class 0.2S, 0.5S or class 1 watt-hour meter or class 2 var-hour meter. Compliance assured by Atmel M90E32AS.

**Wi-Fi**
ESP32 is compliant with EN 301 893.  Officially, you need to retest it as the PCB might alter emission. For full compliance, an option is to drop it or test it.

**Directive 2014/35/EU**
Company is responsible for ensuring that the product meets the necessary legal requirements, and then they affix the CE mark themselves, which is a "declaration of conformity”.  Product operates below 1000V and as such is low-voltage.
As said, I don't think encasing is complaint.

Closed 2025-05-20.

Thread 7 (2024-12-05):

data science feedback

temphstarmans, 2024-12-05:
There are trivial applications one could do with the energy meter data like computing energy consumption.
Less trivial is to detect whether something strange occurs. Obviously you can provide a lot of value to your customer by preventing; production of invalid parts, solar roof is burning, electricity shortage etc. In the following, I would like to briefly outline how this can be done.
I will discuss two approaches; Hidden Markov Models and SPC charts. In the ideal factory situation, your energy monitor would be detected to one say injection molding machine. I guess it is harder if you look at all the machines at the same time.

# Hidden Markov Models

Look at the following example, [Dishonest Casino ](https://hmmlearn.readthedocs.io/en/latest/auto_examples/plot_casino.html), this outlines how you could spot by just looking at the dice rolls whether the dice is loaded or not. Just as casinos analyze die roll patterns to identify irregularities, we can examine the data produced by the energy sensor to pinpoint if our machine is not working correctly.
Basically the procedure is as follows. You collect data from your sensors along time. You resample to say 1 second by taking the mean. Resampling speeds up the calculation. You split your data in a train and test set. For simplicity, I ignore the validation set. You could further simplify by using an one dimensional treatment.
You then fit a Gaussian Hidden Markov upon your data. Your data is not discrete but continuous. You try models with different number of states.   Each models will have a different goodness of fit using the AIC, BIC or LLS criterion. By looking at the the metrics and whether or not the test set delivers the same result as the train set you can see if you find something. Let's say you try models from 2 up to 10 states and see that the best fit is around 4.You then plot the state number along your data. You plot how often the system resides in the state, e.g. by using a fraction. You should then be able to label something like; off, normal, startup and error.

# Statistical Process Control

Another approach would be to use [Statistical Process Control](https://en.wikipedia.org/wiki/Statistical_process_control).
A good intro is [here](https://www.sheffieldmca.org.uk/UserFiles/File/Control_Charts_One_Page_Book_Revised_June_14.pdf) basically you need a package which implements several rules; e.g. outside 3 sigma boundary is outlier point.
Several packages are available [pyspc](https://github.com/carlosqsilva/pyspc) and [statprocon](https://github.com/mattmccormick/statprocon). They seem to be incomplete.

Closed 2025-05-20.

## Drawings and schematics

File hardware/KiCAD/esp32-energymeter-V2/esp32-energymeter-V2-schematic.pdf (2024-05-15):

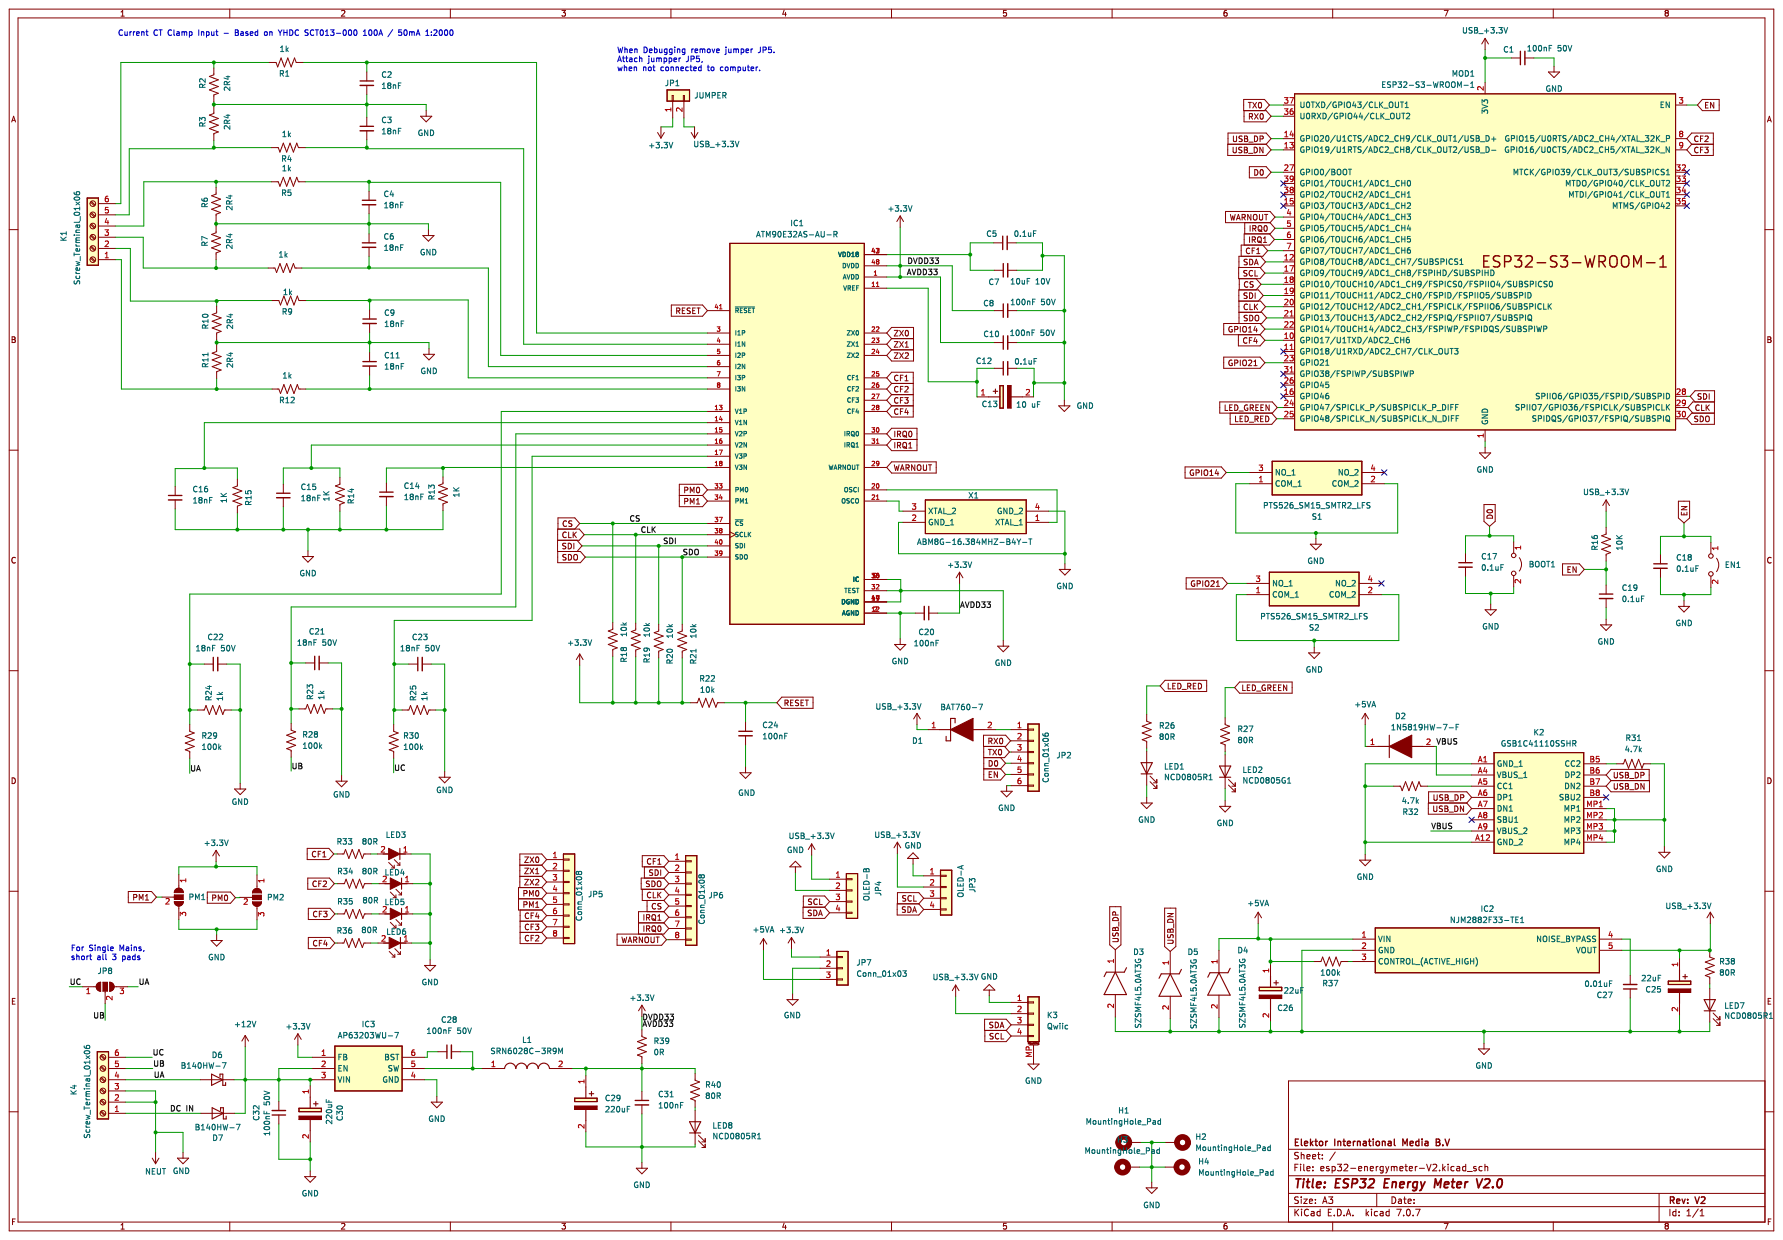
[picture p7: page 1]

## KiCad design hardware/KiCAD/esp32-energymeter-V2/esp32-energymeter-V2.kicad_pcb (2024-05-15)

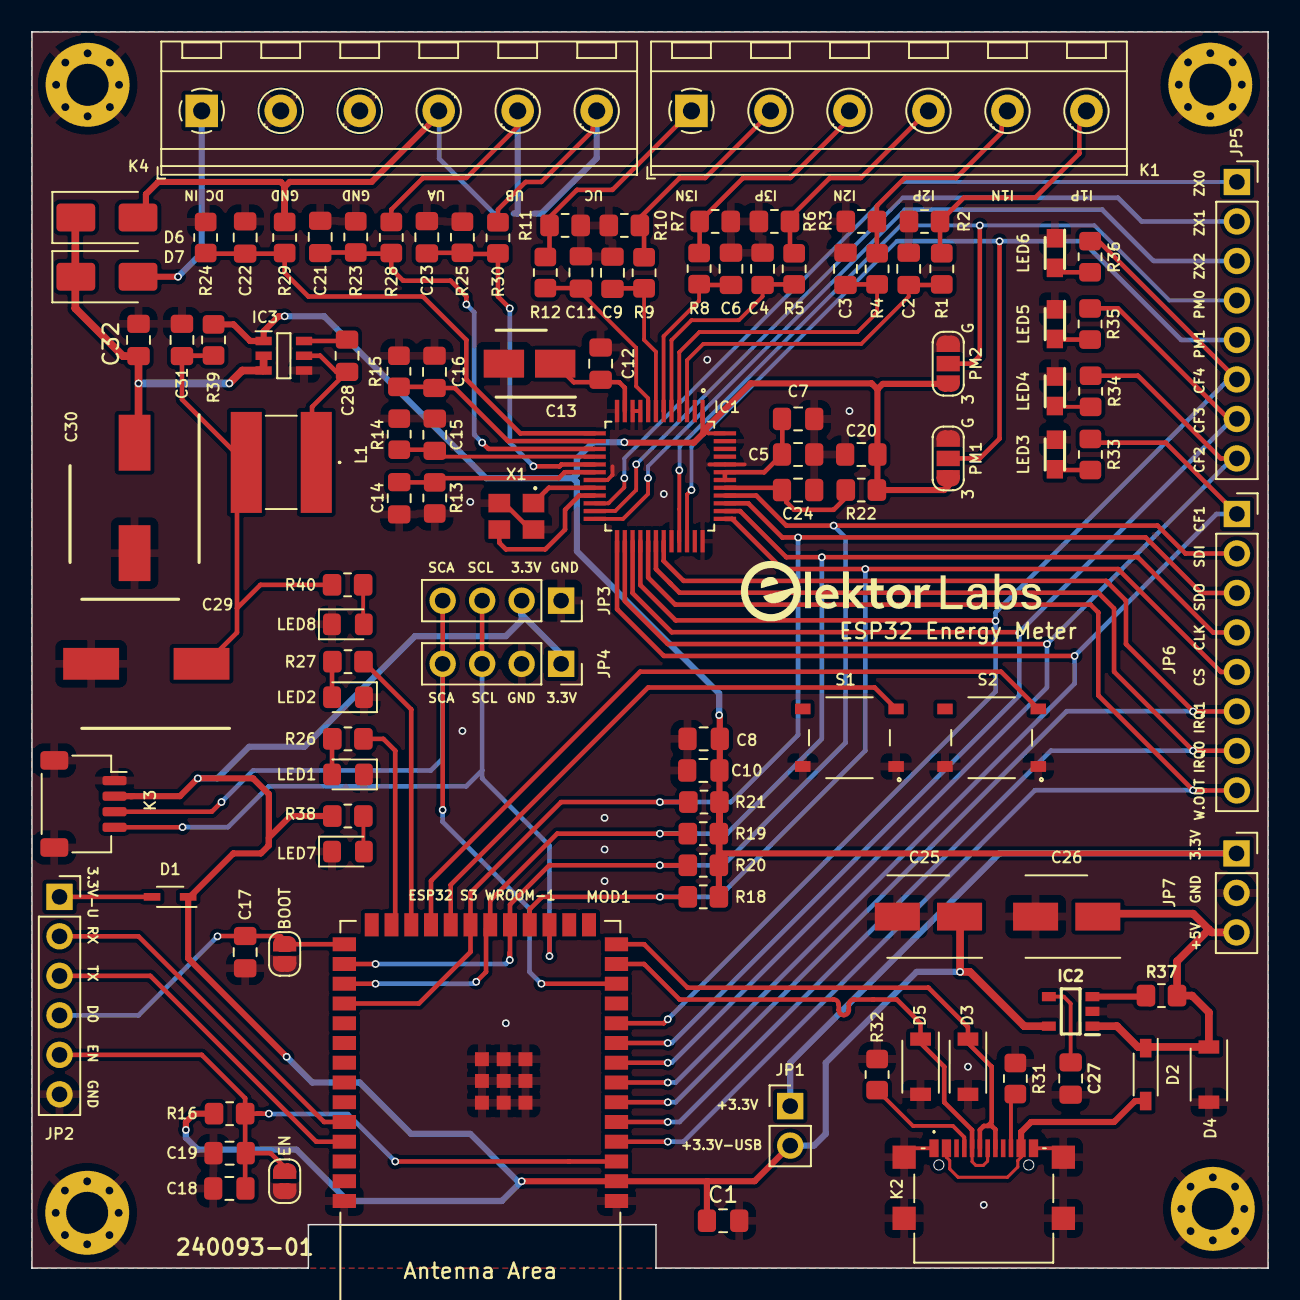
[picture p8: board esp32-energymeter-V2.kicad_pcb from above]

Board: 2 copper layers, 79.5 x 79.5 mm, 114 parts (1 on the bottom side), 77 nets.

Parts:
BOOT1: BOOT; SolderJumper-2_P1.3mm_Open_RoundedPad1.0x1.5mm
C1, C8, C10, C28, C32: 100nF 50V; C_0805_2012Metric_Pad1.18x1.45mm_HandSolder
C2, C3, C4, C6, C9, C11, C14, C15, C16: 18nF; C_0805_2012Metric_Pad1.18x1.45mm_HandSolder
C5, C12, C17, C18, C19: 0.1uF; C_0805_2012Metric_Pad1.18x1.45mm_HandSolder
C7: 10uF 10V; C_0805_2012Metric_Pad1.18x1.45mm_HandSolder
C13: 10 uF; CAPAE430X550N
C20, C24, C31: 100nF; C_0805_2012Metric_Pad1.18x1.45mm_HandSolder
C21, C22, C23: 18nF 50V; C_0805_2012Metric_Pad1.18x1.45mm_HandSolder
C25, C26: 22uF; CAPAE530X550N
C27: 0.01uF; C_0805_2012Metric_Pad1.18x1.45mm_HandSolder
C29, C30: 220uF; CAPAE830X1050N
D1: BAT760-7; SOD2513X120N
D2: 1N5819HW-7-F; SOD3716X145N
D3, D4, D5: SZSMF4L5.0AT3G; SODFL3824X140N
D6, D7: B140HW-7; D_SMA
EN1: EN; SolderJumper-2_P1.3mm_Open_RoundedPad1.0x1.5mm
H1, H2, H3, H4: MountingHole_Pad; MountingHole_2.7mm_Pad_Via
IC1: ATM90E32AS-AU-R; QFP50P900X900X120-48N
IC2: NJM2882F33-TE1; SOT95P280X130-5N
IC3: AP63203WU-7; SOT95P280X100-6N
JP1: JUMPER; PinHeader_1x02_P2.54mm_Vertical
JP2: Conn_01x06; PinSocket_1x06_P2.54mm_Vertical
JP3: OLED-A; PinSocket_1x04_P2.54mm_Vertical
JP4: OLED-B; PinSocket_1x04_P2.54mm_Vertical
JP5, JP6: Conn_01x08; PinSocket_1x08_P2.54mm_Vertical
JP7: Conn_01x03; PinSocket_1x03_P2.54mm_Vertical
JP8: SolderJumper_3_Open; SolderJumper-3_P1.3mm_Open_RoundedPad1.0x1.5mm_NumberLabels
K1, K4: Screw_Terminal_01x06; TerminalBlock_RND_205-00236_1x06_P5.08mm_Horizontal
K2: GSB1C41110SSHR
K3: Qwiic; JST_SH_SM04B-SRSS-TB_1x04-1MP_P1.00mm_Horizontal
L1: SRN6028C-3R9M; SRN6028C3R9M
LED1, LED7, LED8: NCD0805R1; LED_0805_2012Metric_Pad1.15x1.40mm_HandSolder
LED2: NCD0805G1; LED_0805_2012Metric_Pad1.15x1.40mm_HandSolder
LED3: 150080RS75000; LEDM2012X80N
LED4: 150080GS75000; LEDM2012X80N
LED5: 150080BS75000; LEDM2012X80N
LED6: 150080AS75000; LEDM2012X80N
MOD1: ESP32-S3-WROOM-1
PM1, PM2: SolderJumper_3_Open; SolderJumper-3_P1.3mm_Open_RoundedPad1.0x1.5mm_NumberLabels
R1, R4, R5, R8, R9, R12, R23, R24, R25: 1k; R_0805_2012Metric_Pad1.20x1.40mm_HandSolder
R2, R3, R6, R7, R10, R11: 2R4; R_0805_2012Metric_Pad1.20x1.40mm_HandSolder
R13, R14, R15: 1K; R_0805_2012Metric_Pad1.20x1.40mm_HandSolder
R16: 10K; R_0805_2012Metric_Pad1.20x1.40mm_HandSolder
R18, R19, R20, R21, R22: 10k; R_0805_2012Metric_Pad1.20x1.40mm_HandSolder
R26, R27, R33, R34, R35, R36, R38, R40: 80R; R_0805_2012Metric_Pad1.20x1.40mm_HandSolder
R28, R29, R30, R37: 100k; R_0805_2012Metric_Pad1.20x1.40mm_HandSolder
R31, R32: 4.7k; R_0805_2012Metric_Pad1.20x1.40mm_HandSolder
R39: 0R; R_0805_2012Metric_Pad1.20x1.40mm_HandSolder
S1, S2: PTS526_SM15_SMTR2_LFS; PTS526SM15SMTR2LFS
X1: ABM8G-16.384MHZ-B4Y-T; ABM8G

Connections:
+3.3V: C8.1, C10.1, C20.1, IC1.1 (AVDD), IC1.48 (DVDD), IC3.1 (FB), JP1.1, JP7.1, PM1.1 (A), PM2.1 (A), R18.2, R19.2, R20.2, R21.2, R22.1, R39.1
+5VA: C26.1 (+), D2.1 (K), D4.1 (K), IC2.1 (VIN), JP7.3, R37.2
+12V: C30.1 (+), C32.2, D6.1 (K), D7.1 (K), IC3.2 (EN), IC3.3 (VIN)
/DC IN: D7.2 (A), K4.1
/UA: D6.2 (A), JP8.3 (B), K4.4, R29.2
/UB: JP8.2 (C), K4.5, R28.2
/UC: JP8.1 (A), K4.6, R30.2
/VBUS: D2.2 (A), K2.A4 (VBUS_1), K2.A9 (VBUS_2)
CF1: IC1.25 (CF1), JP6.1, MOD1.7 (GPIO7/TOUCH7/ADC1_CH6), R33.2
CF2: IC1.26 (CF2), JP5.8, MOD1.8 (GPIO15/U0RTS/ADC2_CH4/XTAL_32K_P), R34.2
CF3: IC1.27 (CF3), JP5.7, MOD1.9 (GPIO16/U0CTS/ADC2_CH5/XTAL_32K_N), R35.2
CF4: IC1.28 (CF4), JP5.6, MOD1.10 (GPIO17/U1TXD/ADC2_CH6), R36.2
CLK: IC1.38 (SCLK), JP6.4, MOD1.20 (GPIO12/TOUCH12/ADC2_CH1/FSPICLK/FSPIIO6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), MOD1.29 (SPIIO7/GPIO36/FSPICLK/SUBSPICLK), R19.1
CS: IC1.37 (~CS), JP6.5, MOD1.18 (GPIO10/TOUCH10/ADC1_CH9/FSPICS0/FSPIIO4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), R18.1
D0: BOOT1.1 (A), C17.1, JP2.4, MOD1.27 (GPIO0/BOOT)
EN: C18.1, C19.1, EN1.1 (A), JP2.5, MOD1.3 (EN), R16.1
GND: BOOT1.2 (B), C1.2, C2.2, C3.1, C4.2, C5.2, C6.1, C7.2, C8.2, C9.2, C10.2, C11.1, C12.2, C13.2 (-), C14.2, C15.2, C16.2, C17.2, C18.2, C19.2, C20.2, C21.2, C22.2, C23.2, C24.2, C25.2 (-), C26.2 (-), C27.1, C29.2 (-), C30.2 (-), C31.2, C32.1, D3.2 (A), D4.2 (A), D5.2 (A), EN1.2 (B), H1.1, H2.1, H3.1, H4.1, IC1.2 (AGND), IC1.9 (IC), IC1.10 (IC), IC1.12 (AGND), IC1.19 (DGND), IC1.32 (TEST), IC1.36 (IC), IC1.44 (DGND), IC1.47 (DGND), IC2.2 (GND), IC3.4 (GND), JP2.6, JP3.1, JP4.2, JP7.2, K2.A1 (GND_1), K2.A12 (GND_2), K2.MP1, K2.MP2, K2.MP3, K2.MP4, K3.1, K3.MP (MountPin), K4.2, K4.3, LED1.1 (K), LED2.1 (K), LED3.1 (K), LED4.1 (K), LED5.1 (K), LED6.1 (K), LED7.1 (K), LED8.1 (K), MOD1.1 (GND), MOD1.40 (GND), MOD1.41 (GND), PM1.3 (B), PM2.3 (B), R2.1, R3.2, R6.1, R7.2, R10.1, R11.2, R13.1, R14.2, R15.2, R23.1, R24.1, R25.1, R31.1, R32.2, S1.1 (COM_1), S1.2 (COM_2), S2.1 (COM_1), S2.2 (COM_2), X1.2 (GND_1), X1.4 (GND_2)
GPIO14: MOD1.22 (GPIO14/TOUCH14/ADC2_CH3/FSPIWP/FSPIDQS/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), S1.3 (NO_1)
GPIO21: MOD1.23 (GPIO21), S2.3 (NO_1)
IRQ0: IC1.30 (IRQ0), JP6.7, MOD1.5 (GPIO5/TOUCH5/ADC1_CH4)
IRQ1: IC1.31 (IRQ1), JP6.6, MOD1.6 (GPIO6/TOUCH6/ADC1_CH5)
LED_GREEN: MOD1.24 (GPIO47/SPICLK_P/SUBSPICLK_P_DIFF), R27.2
LED_RED: MOD1.25 (GPIO48/SPICLK_N/SUBSPICLK_N_DIFF), R26.2
unnamed: C5.1, C7.1, IC1.42 (VDD18), IC1.43 (VDD18)
unnamed: C12.1, C13.1 (+), IC1.11 (VREF)
unnamed: C29.1 (+), C31.1, L1.2, R39.2, R40.2
unnamed: D1.2 (A), JP2.1
unnamed: C3.2, IC1.4 (I1N), R4.1
unnamed: C2.1, IC1.3 (I1P), R1.1
unnamed: C6.2, IC1.6 (I2N), R8.1
unnamed: C4.1, IC1.5 (I2P), R5.1
unnamed: C11.2, IC1.8 (I3N), R12.1
unnamed: C9.1, IC1.7 (I3P), R9.1
unnamed: IC1.20 (OSCI), X1.1 (XTAL_1)
unnamed: IC1.21 (OSCO), X1.3 (XTAL_2)
unnamed: C16.1, IC1.14 (V1N), R15.1
unnamed: C22.1, IC1.13 (V1P), R24.2, R29.1
unnamed: C15.1, IC1.16 (V2N), R14.1
unnamed: C21.1, IC1.15 (V2P), R23.2, R28.1
unnamed: C14.1, IC1.18 (V3N), R13.2
unnamed: C23.1, IC1.17 (V3P), R25.2, R30.1
unnamed: IC2.3 (CONTROL_(ACTIVE_HIGH)), R37.1
unnamed: C27.2, IC2.4 (NOISE_BYPASS)
unnamed: C28.1, IC3.6 (BST)
unnamed: C28.2, IC3.5 (SW), L1.1
unnamed: K1.1, R11.1, R12.2
unnamed: K1.2, R9.2, R10.2
unnamed: K1.3, R7.1, R8.2
unnamed: K1.4, R5.2, R6.2
unnamed: K1.5, R3.1, R4.2
unnamed: K1.6, R1.2, R2.2
unnamed: K2.A5 (CC1), R32.1
unnamed: K2.B5 (CC2), R31.2
unnamed: LED1.2 (A), R26.1
unnamed: LED2.2 (A), R27.1
unnamed: LED3.2 (A), R33.1
unnamed: LED4.2 (A), R34.1
unnamed: LED5.2 (A), R35.1
unnamed: LED6.2 (A), R36.1
unnamed: LED7.2 (A), R38.1
unnamed: LED8.2 (A), R40.1
PM0: IC1.33 (PM0), JP5.4, PM2.2 (C)
PM1: IC1.34 (PM1), JP5.5, PM1.2 (C)
RESET: C24.1, IC1.41 (~RESET), R22.2
RX0: JP2.2, MOD1.36 (U0RXD/GPIO44/CLK_OUT2)
SCL: JP3.3, JP4.3, K3.4, MOD1.17 (GPIO9/TOUCH9/ADC1_CH8/FSPIHD/SUBSPIHD)
SDA: JP3.4, JP4.4, K3.3, MOD1.12 (GPIO8/TOUCH8/ADC1_CH7/SUBSPICS1)
SDI: IC1.40 (SDI), JP6.2, MOD1.19 (GPIO11/TOUCH11/ADC2_CH0/FSPID/FSPIIO5/S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), MOD1.28 (SPIIO6/GPIO35/FSPID/SUBSPID), R20.1
SDO: IC1.39 (SDO), JP6.3, MOD1.21 (GPIO13/TOUCH13/ADC2_CH2/FSPIQ/FSPIIO7/S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), MOD1.30 (SPIDQS/GPIO37/FSPIQ/SUBSPIQ), R21.1
TX0: JP2.3, MOD1.37 (U0TXD/GPIO43/CLK_OUT1)
USB_+3.3V: C1.1, C25.1 (+), D1.1 (K), IC2.5 (VOUT), JP1.2, JP3.2, JP4.1, K3.2, MOD1.2 (3V3), R16.2, R38.2
USB_DN: D5.1 (K), K2.A7 (DN1), K2.B7 (DN2), MOD1.13 (GPIO19/U1RTS/ADC2_CH8/CLK_OUT2/USB_D-)
USB_DP: D3.1 (K), K2.A6 (DP1), K2.B6 (DP2), MOD1.14 (GPIO20/U1CTS/ADC2_CH9/CLK_OUT1/USB_D+)
WARNOUT: IC1.29 (WARNOUT), JP6.8, MOD1.4 (GPIO4/TOUCH4/ADC1_CH3)
ZX0: IC1.22 (ZX0), JP5.1
ZX1: IC1.23 (ZX1), JP5.2
ZX2: IC1.24 (ZX2), JP5.3

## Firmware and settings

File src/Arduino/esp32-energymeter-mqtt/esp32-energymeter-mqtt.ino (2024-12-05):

/*
 * Project: esp32-energymeter-mqtt
 * 
 * Description:
 * This project is designed to monitor and report energy consumption using an ESP32 microcontroller and the ATM90E32 energy metering IC. 
 * The collected energy data is sent to a Home Assistant server via MQTT. The ESP32 connects to a WiFi network and communicates with 
 * an MQTT broker to publish energy metrics, making it accessible for home automation and monitoring purposes.
 * 
 * Key Features:
 * - Energy Monitoring: Utilizes the ATM90E32 IC to measure voltage, current, and power metrics.
 * - WiFi Connectivity: Connects to a specified WiFi network for seamless integration with IoT systems.
 * - MQTT Communication: Sends energy data to a Home Assistant or other MQTT-compatible platforms for real-time monitoring.
 * - Debugging: Optional serial debugging to assist in development and troubleshooting.
 * 
 * Libraries Used:
 * - ATM90E32 [https://github.com/CircuitSetup/ATM90E32]:  Handles communication with the energy metering IC.
 * - MQTTPubSubClient [https://github.com/hideakitai/MQTTPubSubClient]: Manages MQTT communication for sending data to Home Assistant.
 * 
 * Getting Started:
 * To get started, open the config.ino file and set the following parameters:
 * - WiFi Credentials:
 *   - WIFISSID: Your WiFi network SSID.
 *   - WIFIPASSWORD: Your WiFi network password.
 * - MQTT Broker Configuration:
 *   - HOMEASSISTANT_IP: The IP address of your Home Assistant or MQTT broker.
 *   - DEVICE_NAME: The name of your device.
 *   - USER_ID: The username for your MQTT broker.
 *   - PASSWORD: The password for your MQTT broker.
 * - Debugging:
 *   - DEBUG: Set to true if you want to use the Serial Monitor for debugging.
 * 
 * Author: Saad Imtiaz
 * Date: 25th June, 2024
 */

#include <WiFi.h>
#include <SPI.h>
#include <ATM90E32.h>
#include <MQTTPubSubClient.h>
#include <config.ino> // Include configuration file for WiFi and MQTT details

// WiFi Credentials
const char* ssid = WIFISSID;       // Your WiFi SSID
const char* pass = WIFIPASSWORD;   // Your WiFi Password

WiFiClient client;
MQTTPubSubClient mqtt;

ATM90E32 energymeter{};

void setup() {
  /* Initialize the serial port for debugging if DEBUG is set to true */
  #if DEBUG == true
  Serial.begin(115200);
  Serial.println("Start ATM90E32"); // Debugging message to indicate the start of ATM90E32 initialization
  #endif

  /* Initialize the ATM90E32 energy meter with the specified parameters */
  energymeter.begin(CS_PIN, LINEFREQ, PGA_GAIN, VOLTAGE_GAIN, GAIN_CT_A, GAIN_CT_B, GAIN_CT_C);
  
  /* Set up the GREEN_LED pin as an output and turn it off initially */
  pinMode(GREEN_LED, OUTPUT);
  digitalWrite(GREEN_LED, LOW);

  /* Begin the WiFi connection using the provided SSID and password */
  WiFi.begin(ssid, pass);
  
  /* Initialize the MQTT client */
  mqtt.begin(client);

  /* Connect to WiFi, MQTT broker, and Home Assistant */
  connect();

  /* Set up a subscription to handle incoming MQTT messages */
  mqtt.subscribe([](const String& topic, const String& payload, const size_t size) {
    #if DEBUG == true
    Serial.println("mqtt received: " + topic + " - " + payload); // Debugging message to show received MQTT messages
    #endif
  });

  /* Subscribe to the /hello topic and set up a callback for incoming messages */
  mqtt.subscribe("/hello", [](const String& payload, const size_t size) {
    #if DEBUG == true
    Serial.print("/hello ");
    Serial.println(payload); // Debugging message to show the payload of the /hello topic
    #endif
  });
}

void loop() {
  /* Keep the MQTT client updated */
  mqtt.update();

  /* Reconnect to the MQTT broker if the connection is lost */
  if (!mqtt.isConnected()) {
    connect();
  }

  /* Check and send energy data to Home Assistant every 3 seconds */
  static uint32_t prev_ms = millis();
  if (millis() > prev_ms + 3000) {
    prev_ms = millis();
    getEnergyData(); // Retrieve energy data and send via MQTT
  }
}

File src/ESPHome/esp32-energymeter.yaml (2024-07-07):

esphome:
  name: esp32-energymeter
  friendly_name: esp32_energymeter

esp32:
  board: esp32-s3-devkitc-1
  framework:
    type: arduino


# Enable logging
logger:

# Enable Home Assistant API
api:
  encryption:
    key: "xxxx"

ota:
  password: "xxxx"

wifi:
  ssid: !secret wifi_ssid
  password: !secret wifi_password

  # Enable fallback hotspot (captive portal) in case wifi connection fails
  ap:
    ssid: "xxx"
    password: "xxx"

captive_portal:

i2c:
  sda: GPIO8 
  scl: GPIO9 
  scan: True


spi:
  clk_pin: GPIO12
  miso_pin: GPIO13
  mosi_pin: GPIO11

sensor:
  - platform: atm90e32
    cs_pin: GPIO10
    phase_a:
      voltage:
        name: "Line Voltage A"
        id: VAC
      current:
        name: "CT1 Current"
        id: ct1Amps
      power:
        name: "Active Power CT1"
      reactive_power:
        name: "Reactive Power CT1"
      power_factor:
        name: "Power Factor CT1"
      gain_voltage: 59598
      gain_ct: 64596
    phase_b:
      voltage: 
        name: "Line Voltage B"
        id: VBC
      current:
        name: "CT2 Current"
        id: ct2Amps
      power:
        name: "Active Power CT2"
      reactive_power:
        name: "Reactive Power CT2"
      power_factor:
        name: "Power Factor CT2"
      gain_voltage: 59417 
      gain_ct: 60366
    phase_c:
      voltage: 
        name: "Line Voltage C"
        id: VCC
      current:
        name: " CT3 Current"
        id: ct3Amps
      power:
        name: "Active Power CT3"
      reactive_power:
        name: "Reactive Power CT3"
      power_factor:
        name: "Power Factor CT3"
      gain_voltage: 59365
      gain_ct: 61366
    frequency:
      name: "Line Frequency"
    chip_temperature:
      name: "Chip Temperature"
    line_frequency: 50Hz
    current_phases: 2
    gain_pga: 2X
    update_interval: 5s

#Watts per channel
  - platform: template
    name: CT1 Watts
    id: ct1Watts
    lambda: return id(ct1Amps).state * id(VAC).state;
    accuracy_decimals: 0
    unit_of_measurement: W
    icon: "mdi:flash-circle"
    update_interval: 5s
  - platform: template
    name: CT2 Watts
    id: ct2Watts
    lambda: return id(ct2Amps).state * id(VCC).state;
    accuracy_decimals: 0
    unit_of_measurement: W
    icon: "mdi:flash-circle"
    update_interval: 5s
  - platform: template
    name: CT3 Watts
    id: ct3Watts
    lambda: return id(ct3Amps).state * id(VCC).state;
    accuracy_decimals: 0
    unit_of_measurement: W
    icon: "mdi:flash-circle"
    update_interval: 5s
#Total Amps
  - platform: template
    name: Total Amps
    id: totalAmps
    lambda: return id(ct1Amps).state + id(ct2Amps).state + id(ct3Amps).state;
    accuracy_decimals: 2
    unit_of_measurement: A
    icon: "mdi:flash"
    update_interval: 5s
#Total Watts
  - platform: template
    name: Total Watts
    id: totalWatts
    lambda: return id(totalAmps).state * id(VAC).state;
    accuracy_decimals: 1
    unit_of_measurement: W
    icon: "mdi:flash-circle"
    update_interval: 5s
#kWh
  - platform: total_daily_energy
    name: Total kWh
    power_id: totalWatts
    filters:
      - multiply: 0.001
    unit_of_measurement: kWh

time:
  - platform: sntp
    id: sntp_time
  

display:
  - platform: ssd1306_i2c
    model: "SSD1306 128x64"
    reset_pin: 16  # Change to your OLED's reset pin if needed
    address: 0x3C  # Typically 0x3C or 0x3D, check your device specifications
    rotation: 180

    lambda: |-
      it.strftime(0, 0, id(roboto_medium), TextAlign::TOP_LEFT, "%H:%M:%S", id(sntp_time).now());
      it.printf(0, 10, id(roboto_medium), TextAlign::TOP_LEFT, "Total kW: %.3f", id(totalWatts).state * 0.001);
      it.printf(0, 25, id(roboto_medium), TextAlign::TOP_LEFT, "CA: %.1f A", id(ct1Amps).state);
      it.printf(45, 25, id(roboto_medium), TextAlign::TOP_LEFT, "CB: %.1f A", id(ct2Amps).state);
      it.printf(90, 25, id(roboto_medium), TextAlign::TOP_LEFT, "CC: %.1f A", id(ct3Amps).state);
      it.printf(0, 40, id(roboto_medium), TextAlign::TOP_LEFT, "VA: %.1f V", id(VAC).state);
      it.printf(70, 40, id(roboto_medium), TextAlign::TOP_LEFT, "VB: %.1f V", id(VBC).state);
      it.printf(0, 50, id(roboto_medium), TextAlign::TOP_LEFT, "VC: %.1f V", id(VCC).state);

font:
  - file: "fonts/Roboto-Medium.ttf"
    id: roboto_medium
    size: 8

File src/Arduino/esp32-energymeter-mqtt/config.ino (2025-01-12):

#define DEBUG true  // Make this false if Serial Monitor is not required.

#define WIFISSID "xxx"
#define WIFIPASSWORD "xxxx"

#define HOMEASSISTANT_IP "xxxx"
#define DEVICE_NAME "esp32-energymeter"
#define USER_ID "xxxx"
#define PASSWORD "xxxx"

/***** CALIBRATION SETTINGS *****/
/* 
 * 4485 for 60 Hz
 * 389 for 50 Hz
 */

#define LINEFREQ 389

/* 
 * 0 for 1x (CTs up to 60mA/720mV)
 * 21 for 2x (CTs up to 30mA/360mV)
 * 42 for 4x (CTs up to 15mA/180mV)
 */
#define PGA_GAIN 21

#define VOLTAGE_GAIN 3920

/*
 * 25498 - SCT-013-000 100A/50mA
 * 39473 - SCT-016 120A/40mA
 */
 
#define GAIN_CT_A 39473
#define GAIN_CT_B 39473
#define GAIN_CT_C 39473

#define CS_PIN 10
/*
  12 - CLK
  13 - MISO
  11 - MOSI
*/ 
#define GREEN_LED 47

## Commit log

2024-06-25 updated the BOM
    Mentioned which components should NOT be replaced. The ones with "x" should not be replated with equivalent components.
    [mouser-bom-esp32-energymeter-V2.csv]
2024-06-25 added mechanical and drawing files
    Added Mechanical and Drawing files.
    > PDF Drawing file
    > DWG
    > DXF
    > .STEP [file of the entire PCB]
    [esp32-energymeter-V2.DWG, esp32-energymeter-V2.DXF]
2024-06-26 minor fix
    there were some resistors in the schematic where there was a typo, it was "10K" it should be "10k".
    [esp32-energymeter-V2.kicad_sch]
2024-07-07 Update esp32-energymeter.yaml
    The id CT2 and CT3 were interchanged.
2024-07-31 updated bom
    updated bom lists, mouser and main project bom.
    [esp32-energymeter-V2.csv, esp32-energymeter-V2.kicad_sch, mouser-bom-esp32-energymeter-V2.csv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]
2024-08-05 bom update
    [mouser-bom-esp32-energymeter-V2.csv, mouser-bom-esp32-energymeter-V2.xlsx]
2024-11-18 added
    STL files of the enclosure for the energy meter.
    [Enclosure_base-v1.STL, Enclosure_top-cover-v1.STL]
2024-12-05 updated
    Added the Arduino IDE based code for the ESP32 Energy Meter that sends data to Home Assistant via MQTT.
